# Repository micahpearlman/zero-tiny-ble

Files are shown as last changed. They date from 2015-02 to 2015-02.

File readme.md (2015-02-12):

## Overview

The Zero Tiny BLE is a small low cost and low powered embeddable board with an AVR ATTiny85 microcontroller and a Bluetooth 4.0 (Bluetooth Low Energy or BLE) radio.

* AVR ATTiny85 microcontroller running at 8MHz internal clock and 3.3V. [ATTiny85 Datasheet](http://www.atmel.com/images/atmel-2586-avr-8-bit-microcontroller-attiny25-attiny45-attiny85_datasheet.pdf).
* HM-10 Bluetooth 4.0 Low Energy module.  [HM-10 Datasheet](http://www.jnhuamao.cn/bluetooth40_en.zip).
* Powered by single cell 3.7V Lithium Polymer battery (LiPo) or USB B mini port.
* LiPo battery recharge capabilities via the USB B mini port.
* Standard UART communication over Bluetooth 4.0.
* Easy prototyping via breadboard.
* Use either Arduino or AVR-GCC development environments.
* Small form factor of 20mm x 47mm (0.79” x 1.85”)
* You can purchase a complete board at [Tindie](https://www.tindie.com/products/micahpearlman/zero-tiny-ble/)
* You can order unpopulated boards from [OSH Park](https://oshpark.com/shared_projects/1aQHSlM2)

## Why?

This is a project that fell out of developing sensors (Exhaust Gas Temp, RPM, Lap Timer, etc) for my vintage road racing motorcycle.  I also wanted to use my iOS device as the display and data logger.  So I needed a small, cheap and general purpose board that had  uC and BLE capabilities and could be powered by a small LiPo battery (and be charged by a USB connection).  The HM-10 BLE was super cheap and incredibly easy to integrate. The ATTiny85 is also super cheap, requires practically zero external components when running on it's internal oscillator and can be programmed in the Arduino IDE. 

## Pinouts
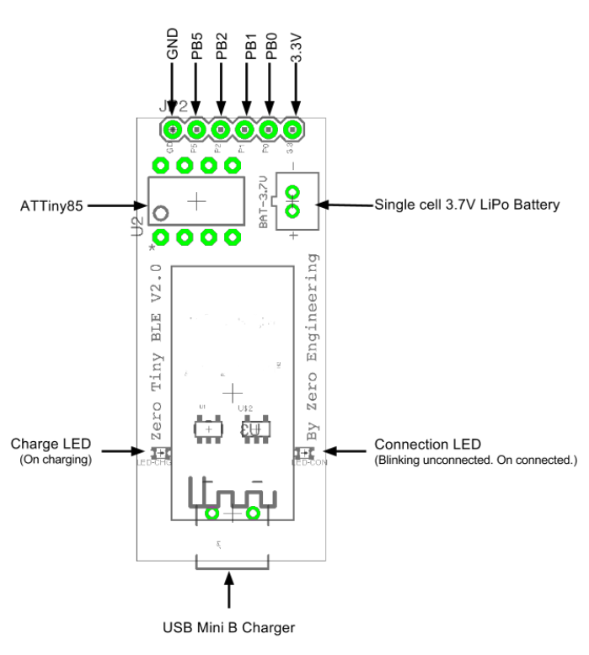
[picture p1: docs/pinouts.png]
what Pin Outs


## Programming Notes
* See our [Getting Started Guide](https://github.com/micahpearlman/zero-tiny-ble/blob/master/docs/zero-tiny-ble-getting-started-guide.md)
* The ATTiny85 cannot be programmed in circuit.  It must be removed and a separate programmer such as the excellent [Sparkfun Tiny AVR Programmer](https://www.sparkfun.com/products/11801).  
* The ATTiny85 pins PB3 (RX) and PB4 (TX) are used for serial communication with the Bluetooth 4.0 radio.
* The ATTiny85 does not have hardware UART serial.  The Arduino SoftwareSerial library should be used. Example:

```
#  define rxPin 3
#  define txPin 4
SoftwareSerial _bluetoothSerial = SoftwareSerial(rxPin, txPin);

void setup() {
	// initialize serial communications at 9600 bps:
	_bluetoothSerial.begin(9600);
}

void loop() {
	_bluetoothSerial.print(“Hello World”);
}
```

* Important: make sure that when programming your ATiny85 in the Arduino IDE that the board is set to “ATTiny85 (internal 8MHz)”

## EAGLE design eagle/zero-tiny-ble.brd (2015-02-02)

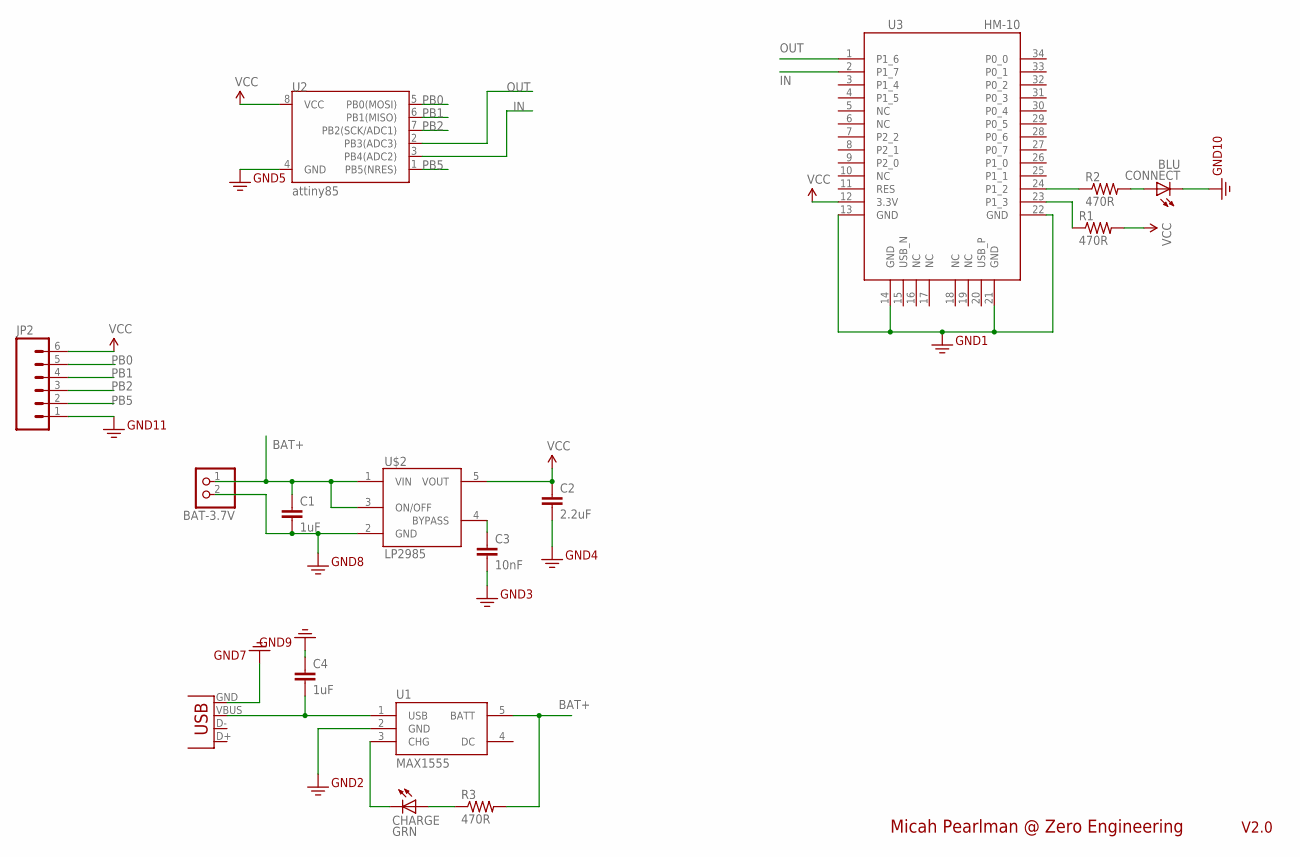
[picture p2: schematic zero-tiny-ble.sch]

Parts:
BAT-3.7V: JST_2PIN-THM; JST-PH-2-THM
C1, C4: 1uF; 0805
C2: 2.2uF; 0805
C3: 10nF; 0805
CHARGE: GRN; CHIPLED_0805
CONNECT: BLU; CHIPLED_0805
JP1: USB-SMD-NS; USB-MINIB-NOSTOP
JP2: M06SILK_FEMALE_PTH; 1X06
R1, R2, R3: 470R; 0805
U1: MAX1555; SOT23-5
U2: attiny85; DIP08
U3: HM-10
U$2: LP2985AIM5-3.3; SOT25

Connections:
3.3V: BAT-3.7V.2 (1), C1.2, C2.2, C3.2, C4.1, CONNECT.C, JP1.GND, JP2.1, U1.2 (GND), U2.4 (GND), U3.13 (GND), U3.14 (GND), U3.21 (GND), U3.22 (GND), U$2.2 (GND)
BAT+: BAT-3.7V.1 (2), C1.1, R3.2, U1.5 (BATT), U$2.1 (VIN), U$2.3 (ON/OFF)
BYPASS: C3.1, U$2.4 (BYPASS)
IN: U2.3 (PB4(ADC2)), U3.2 (P1_7)
unnamed: CHARGE.A, R3.1
unnamed: C4.2, JP1.VBUS, U1.1 (USB)
unnamed: CHARGE.C, U1.3 (CHG)
unnamed: R2.1, U3.24 (P1_2)
unnamed: R1.1, U3.23 (P1_3)
unnamed: CONNECT.A, R2.2
OUT: U2.2 (PB3(ADC3)), U3.1 (P1_6)
PB0: JP2.5, U2.5 (PB0(MOSI))
PB1: JP2.4, U2.6 (PB1(MISO))
PB2: JP2.3, U2.7 (PB2(SCK/ADC1))
PB5: JP2.2, U2.1 (PB5(NRES))
VCC: C2.1, JP2.6, R1.2, U2.8 (VCC), U3.12 (3.3V), U$2.5 (VOUT)

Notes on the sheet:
Micah Pearlman @ Zero Engineering
V2.0

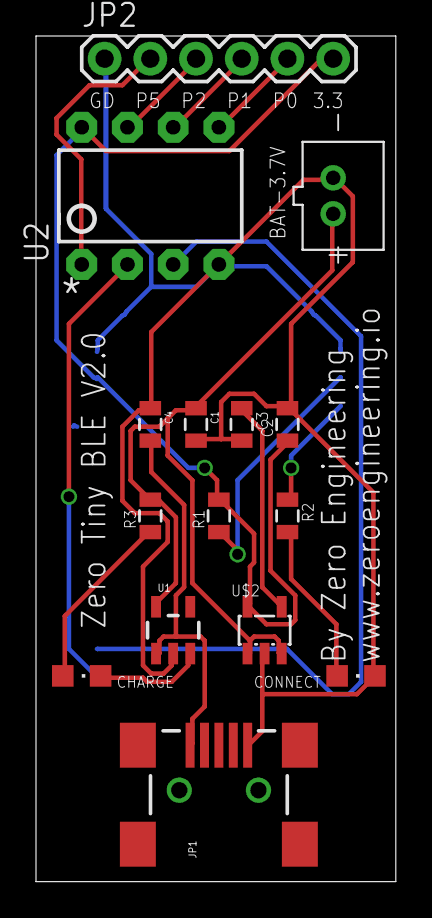
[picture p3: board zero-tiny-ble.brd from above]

Board: 2 copper layers, 20.0 x 47.0 mm, 16 parts (1 on the bottom side), 16 nets.

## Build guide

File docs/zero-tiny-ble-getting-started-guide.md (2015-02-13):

# Zero Tiny BLE Getting Started Guide

## Before You Get Started

You will need the following:

* USB mini B cable for power -OR- a 3.7V single cell LiPo battery with a JST PH 2 pin connector. [Adafruit sells a nice 3.7V 150mAH battery](https://www.adafruit.com/products/1317).
* [Arduino IDE](http://arduino.cc/en/Main/Software).  _Note: that the ATTiny85 is flashed with an Arduino bootloader_
* A programmer for the Atmel AVR ATTiny85 microcontroller.
	* [SparkFun Tiny AVR Programmer](https://www.sparkfun.com/products/11801)
	* [High-Low Tech has an excellent article on using an Arduino Duo as a programmer](http://highlowtech.org/?p=1706)
	* There are also a ton of low cost options on EBay as well.
* For iOS you will need [XCode with the iOS SDK](https://developer.apple.com/devcenter/ios/index.action).
* Example code and upto date documents on the [Zero Tiny BLE Github](https://github.com/micahpearlman/zero-tiny-ble)

## Powering Up Your Zero Tiny BLE

* Plug in a USB mini B cable -OR- 3.7V LiPo battery.
* You should see a blinking blue LED.  This means that the Bluetooth radio is up and running.  When solid blue that means Bluetooth is connected.
* _IF_ you have both a LiPo battery and a the USB plugged in you will see a green LED.  This means that the USB is charging the battery _and_ powering the board.

## Setting Up Arduino Environment for ATTiny85

_Instructions are derived from [High-Low Tech tutorial](http://highlowtech.org/?p=1695)._

1. Download and install the [Arduino IDE](http://arduino.cc/en/Main/Software)
2. Download the [ATTiny hardware files](https://github.com/damellis/attiny/archive/master.zip) for the Arduino.
3. Unzip the attiny master.zip file. It should contain an “attiny-master” folder that contains an “attiny” folder.
4. Locate your Arduino sketchbook folder (you can find its location in the preferences dialog in the Arduino software)
5. Create a new sub-folder called “hardware” in the sketchbook folder, if it doesn’t exist already.
6. Copy the “attiny” folder (not the attiny-master folder) from the unzipped ATtiny master.zip to the “hardware” folder. You should end up with folder structure like Documents > Arduino > hardware > attiny that contains the file boards.txt and another folder called variants.
7. Restart the Arduino development environment.
8. You should see ATtiny entries in the Tools > Board menu. Important: make sure that when programming your ATiny85 in the Arduino IDE that the board is set to “ATTiny85 (internal 8MHz)”

## Hello World on the Arduino

1. Download the [Hello World example sketch](https://github.com/micahpearlman/zero-tiny-ble/tree/master/arduino-example/hello-world)
2. Open this up in the Arduino IDE and compile and run using your chosen ATTiny85 programmer.

## Setting up the ZOBluetoothUART iOS Project

1. Download the [ZOBluetoothUART project from GitHub](https://github.com/micahpearlman/zero-tiny-ble/tree/master/ios-examples/ZOBluetoothUART).
2. Power up your Zero Tiny BLE.
3. Compile and run from XCode.
4. The Zero Tiny BLE blue LED should change from blinking to always on.  This means you are connected.
5. You should see "Hello Zero Tiny!" printing out every second.

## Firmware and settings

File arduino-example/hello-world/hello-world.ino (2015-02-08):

/*
 
 created: 11-22-2014
 by Micah Pearlman
 micah@zeroengineering.io
 www.zeroengineering.io
 
 This is BSD licensed
 
 */
// attiny85 uses software serial
#include <SoftwareSerial.h>
#  define rxPin 3
#  define txPin 4 // NOTE: pin 3 is equal to physical pin 2: see http://fc04.deviantart.net/fs70/f/2013/038/3/7/attiny_web_by_pighixxx-d5u4aur.png
  SoftwareSerial _bluetoothSerial = SoftwareSerial(rxPin, txPin);


void setup() {
  
  // initialize serial communications at 9600 bps:
  _bluetoothSerial.begin(9600); 

  delay(100); 
}


void loop() {
  _bluetoothSerial.println("Hello Zero Tiny!");     

  // delay for 1 second
  delay(1000);  
}

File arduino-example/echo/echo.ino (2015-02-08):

/*
 
 created: 11-22-2014
 by Micah Pearlman
 micah@zeroengineering.io
 www.zeroengineering.io
 
 This is BSD licensed
 
 */
// attiny85 uses software serial
#include <SoftwareSerial.h>
#  define rxPin 3
#  define txPin 4 // NOTE: pin 3 is equal to physical pin 2: see http://fc04.deviantart.net/fs70/f/2013/038/3/7/attiny_web_by_pighixxx-d5u4aur.png
  SoftwareSerial _bluetoothSerial = SoftwareSerial(rxPin, txPin);


void setup() {
  
  // initialize serial communications at 9600 bps:
  _bluetoothSerial.begin(9600); 
  


  // initialize HM-10 (see datasheet)
  // set mode 2:
  // Mode 2:
  // Before establishing a connection, you can use the AT command configuration module through UART.
  // After established a connection, you can send data to remote side. Remote side can do fellows:
  // Send AT command configuration module.
  // Remote control PIO2 to PIO11 pins output state of HM-10.
  // Remote control PIO2, PIO3 pins output state of HM-11.
  // Send data to module UART port (not include any AT command and per
  // package must less than 20 bytes).
  // set the name
  delay(100);  
  _bluetoothSerial.write("AT+NAMEZeroTiny");
  delay(100);  
  _bluetoothSerial.write("AT+MODE2");
  delay(100);  
  _bluetoothSerial.write("AT+RESET");
  delay(100); 

}


#define BUFFER_SIZE 64
char buffer[BUFFER_SIZE];
void loop() {
   // fill up a read buffer  
   int buffer_cnt = 0;
   while(_bluetoothSerial.available() && buffer_cnt != BUFFER_SIZE) {
       buffer[buffer_cnt] = _bluetoothSerial.read();
       buffer_cnt++;
       delay(20);  
   }
   
   // if we read the buffer echo it back
   if ( buffer_cnt > 0 ) {
      buffer[buffer_cnt] = '\0'; // terminate string
      _bluetoothSerial.print(buffer);     
   }
  

  delay(100);  
}

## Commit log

2015-02-02 updated silk screen.
    [zero-tiny-ble.brd, zero-tiny-ble.sch]
2015-02-07 arduino echo example
2015-02-08 fixed arduino echo example
    [echo.ino]

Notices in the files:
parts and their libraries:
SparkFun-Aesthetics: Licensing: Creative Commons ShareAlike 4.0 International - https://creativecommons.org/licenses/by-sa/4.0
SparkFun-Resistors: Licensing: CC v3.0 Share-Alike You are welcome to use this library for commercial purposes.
